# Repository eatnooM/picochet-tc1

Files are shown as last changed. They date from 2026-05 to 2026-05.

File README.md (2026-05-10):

# Picochet-TC1

A dedicated microcontroller board for use with the OpenFIRE firmware, tailored to fit in a Namco Time Crisis 1-3 or Point Blank arcade gun.

Picture of Picochet board

The goal of this project is to allow for clean builds in these guns while retaining support for driving the gun's solenoid
(not a big fan of multiple boards floating around in the shell)
and to serve as a base for future Picochet boards in other light guns where a carrier board using a Raspberry Pi Pico or similar would be tricky or impossible.

## BOM

| Reference | Part desc / number | Quantity | Notes |
|---|---|---|---|
| C1,C5,C19,C21 | 10uF 0805 - [LCSC](https://www.lcsc.com/product-detail/C95841.html) | 4 | |
| C6,C7,C9,C10 | 4.7uF 0402 - [LCSC](https://www.lcsc.com/product-detail/C23733.html) | 4 | |
| C8,C11,C12,C13,C14,C15,C16,C17,C18,C20,C26 | 0.1uF 0402 - [LCSC](https://www.lcsc.com/product-detail/C307331.html) | 11 | May want to replace C26 with a THT cap directly on the TMP36 pins |
| C3,C4 | 15pF 0402 - [LCSC](https://www.lcsc.com/product-detail/C86285.html) | 2 | |
| D1 | SOD-323F Schottky - [LCSC](https://www.lcsc.com/product-detail/C552826.html)  | 1 | |
| D2 | RBR3LAM60B - [LCSC](https://www.lcsc.com/product-detail/C509954.html) | 1 | Can also be added at D3 if your solenoid has no flyback diode |
| F1 | PPTC-6V 500mA - [LCSC](https://www.lcsc.com/product-detail/C269104.html) | 1 | |
| L1 | AOTA-B201610S3R3 - [LCSC](https://www.lcsc.com/product-detail/C42411119.html) | 1 | |
| Q1,Q2 | DMT12H060LFDF - [LCSC](https://www.lcsc.com/product-detail/C5711753.html) | 2 | |
| R2,R4,R6,R14,R16 | 1K 0402 - [LCSC](https://www.lcsc.com/product-detail/C11702.html) | 5 | |
| R15,R17 | 100K 0402 - [LCSC](https://www.lcsc.com/product-detail/C60491.html) | 2 | |
| R5 | 33Ω 0402 - [LCSC](https://www.lcsc.com/product-detail/C138002.html) | 1 | |
| R7,R8 | 27Ω 0402 - [LCSC](https://www.lcsc.com/product-detail/C138021.html) | 2 | |
| U1 | RP2354A - [LCSC](https://www.lcsc.com/product-detail/C41378174.html) | 1 | |
| U2 | NCP1117-3.3_SOT223 - [LCSC](https://www.lcsc.com/product-detail/C26537.html) | 1 | |
| Y1 | ABM8-272-T3 - [LCSC](https://www.lcsc.com/product-detail/C20625731.html) | 1 | |
| SW1,SW2 | 4x3mm push button - [LCSC](https://www.lcsc.com/product-detail/C455280.html) | 2 | |

Optional components (see Notes): 
| Reference | Part desc / number | Quantity | Notes |
|---|---|---|---|
| TMP | TMP36 - [LCSC](https://www.lcsc.com/product-detail/C5692995.html) | 1 | Recommended - run wires to this and attach to solenoid |
| C24,C25 | 0.1uF 0805 - [LCSC](https://www.lcsc.com/product-detail/C1711.html) | 2 | Installation not recommended |

## Thanks

OpenFIRE project - https://openfirelightgun.org/

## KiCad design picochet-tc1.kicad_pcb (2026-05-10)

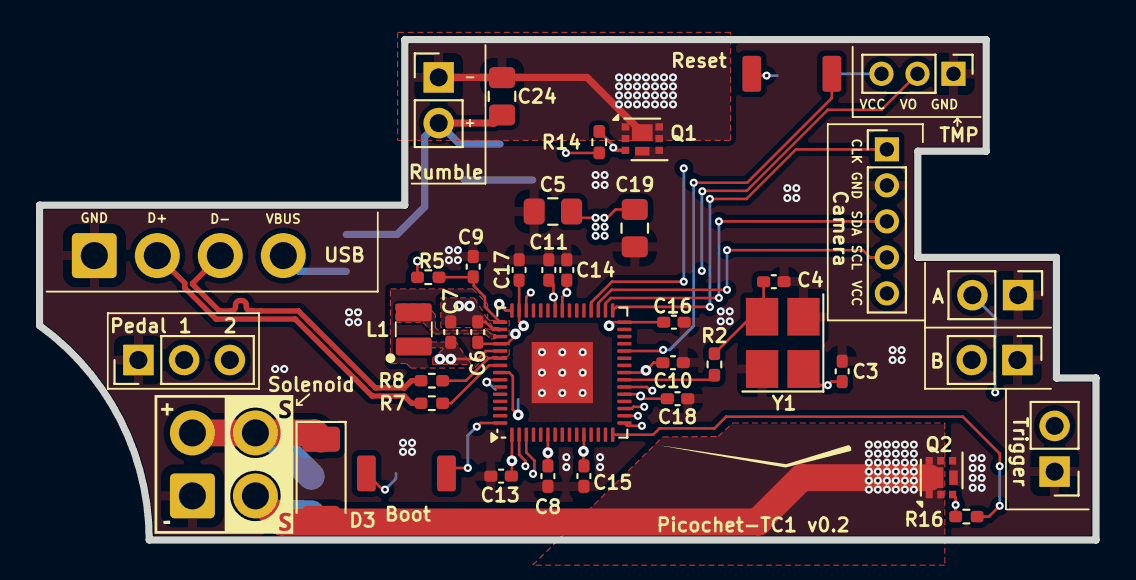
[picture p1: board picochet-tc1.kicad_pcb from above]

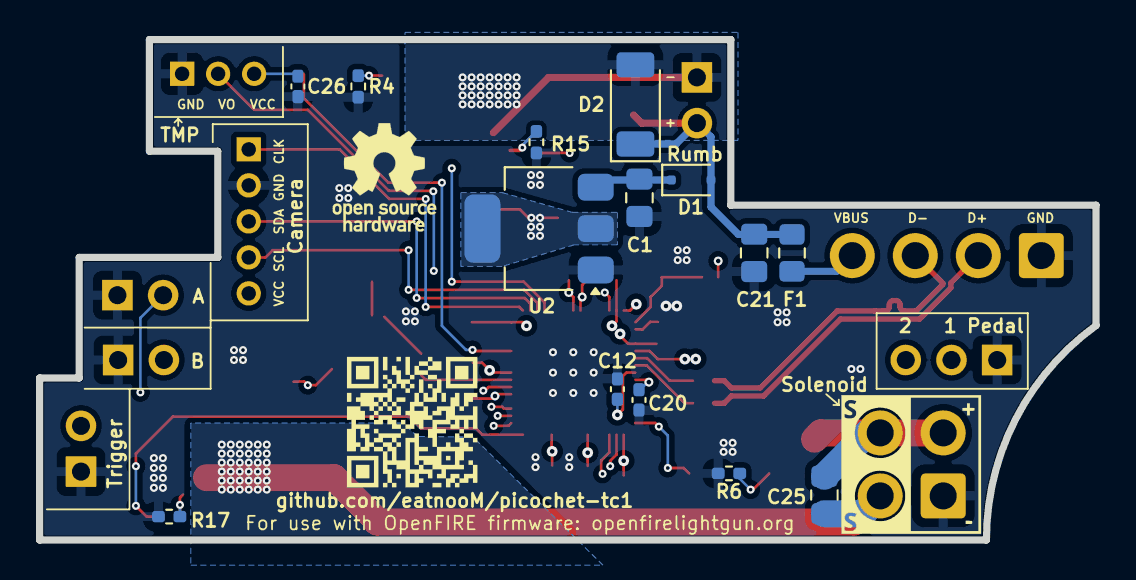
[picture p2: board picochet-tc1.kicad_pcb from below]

Board: 4 copper layers, 58.7 x 27.8 mm, 55 parts (15 on the bottom side), 35 nets.

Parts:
C1, C5, C19, C21: 10uF; C_0805_2012Metric_Pad1.18x1.45mm_HandSolder
C3, C4: 15pF; C_0402_1005Metric_Pad0.74x0.62mm_HandSolder
C6, C7, C9, C10: 4.7uF; C_0402_1005Metric_Pad0.74x0.62mm_HandSolder
C8, C11, C12, C13, C14, C15, C16, C17, C18, C20, C26: 100nF; C_0402_1005Metric_Pad0.74x0.62mm_HandSolder
C24, C25: 100nF; C_0805_2012Metric_Pad1.18x1.45mm_HandSolder
D1: D_Schottky; D_SOD-323F
D2, D3: RBR3LAM60B; D_SOD-128
F1: PPTC-6V 500mA; Fuse_0805_2012Metric_Pad1.15x1.40mm_HandSolder
J1, J2, J4, J9: Conn_01x02; PinHeader_1x02_P2.54mm_Vertical
J3: Conn_01x04; USB-PTH-2.5MMOD-3.5mmSpacing
J5: Conn_02x02; 02x02_PTH-2.5MMOD-3.5mmSpacing
J6: Conn_01x05; PinHeader_1x05_P2.00mm_Vertical
J7: Conn_01x03; PinHeader_1x03_P2.00mm_Vertical
J8: Conn_01x03; PinHeader_1x03_P2.54mm_Vertical
L1: AOTA-B201610S3R3; L_0806_PolarityMark
Q1, Q2: DMT12H060LFDF; Diodes_UDFN2020-6_Type-F
QR*****: github.com/eatnooM/picochet-tc1; picochet-tc1-repo-qr
R2, R4, R6, R14, R16: 1K; R_0402_1005Metric_Pad0.72x0.64mm_HandSolder
R5: 33R; R_0402_1005Metric_Pad0.72x0.64mm_HandSolder
R7, R8: 27R; R_0402_1005Metric_Pad0.72x0.64mm_HandSolder
R15, R17: 100K; R_0402_1005Metric_Pad0.72x0.64mm_HandSolder
SW1, SW2: SW_Push; Switch-Push-SMD-4mmx3mm
U1: RP2354A; QFN-60-1EP_7x7mm_P0.4mm_EP3.4x3.4mm
U2: NCP1117-3.3_SOT223; SOT-223-3_TabPin2
Y1: ABM8-272-T3; Crystal_SMD_3225-4Pin_3.2x2.5mm_HandSoldering

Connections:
+1V1: C7.2, C8.2, C10.2, C11.2, L1.1, U1.6 (DVDD), U1.23 (DVDD), U1.39 (DVDD), U1.50 (VREG_FB)
+3V3: C5.1, C6.2, C12.2, C13.2, C14.2, C15.2, C16.2, C17.1, C18.2, C19.1, C20.2, C26.1, J6.5, J7.3, R5.1, U1.1 (IOVDD), U1.11 (IOVDD), U1.20 (IOVDD), U1.30 (IOVDD), U1.38 (IOVDD), U1.44 (ADC_AVDD), U1.45 (IOVDD), U1.49 (VREG_VIN), U1.53 (USB_OTP_VDD), U1.54 (QSPI_IOVDD), U2.2 (VO)
+5V: C21.1, C24.2, D1.2 (A), D2.1 (K), F1.2, J1.2
/CAM_CLK: J6.1, U1.31 (GPIO19)
/CAM_SCL: J6.4, U1.33 (GPIO21)
/CAM_SDA: J6.3, U1.32 (GPIO20)
/RMB_GND: C24.1, D2.2 (A), J1.1, Q1.1 (D), Q1.2 (D), Q1.5 (D), Q1.6 (D), Q1.7 (D)
/RUMBLE: R14.1, U1.34 (GPIO22)
/SOLENOID: R16.1, U1.15 (GPIO11)
/SOL_GND: C25.1, D3.2 (A), J5.2, Q2.1 (D), Q2.2 (D), Q2.5 (D), Q2.6 (D), Q2.7 (D)
/TMP: J7.2, U1.43 (GPIO29/ADC3)
/USB_D+: J3.2, R7.1
/USB_D-: J3.3, R8.1
/VREG_LX: L1.2, U1.48 (VREG_LX)
/~BTN_A: J4.2, U1.17 (GPIO13)
/~BTN_B: J9.2, U1.18 (GPIO14)
/~BTN_PEDAL_1: J8.2, U1.2 (GPIO0)
/~BTN_PEDAL_2: J8.3, U1.3 (GPIO1)
/~BTN_TRIGGER: J2.2, U1.16 (GPIO12)
/~RESET: SW2.2, U1.26 (RUN)
GND: C1.2, C3.1, C4.1, C5.2, C6.1, C7.1, C8.1, C9.1, C10.1, C11.1, C12.1, C13.1, C14.1, C15.1, C16.1, C17.2, C18.1, C19.2, C20.1, C21.2, C26.2, J2.1, J3.1, J4.1, J5.1, J6.2, J7.1, J8.1, J9.1, Q1.4 (S), Q1.8 (S), Q2.4 (S), Q2.8 (S), R4.1, R6.1, R15.1, R17.1, U1.47 (VREG_PGND), U1.61 (GND), U2.1 (GND), Y1.2 (G), Y1.4 (G)
unnamed: C4.2, R2.1, Y1.3
unnamed: Q1.3 (G), R14.2, R15.2
unnamed: Q2.3 (G), R16.2, R17.2
unnamed: R4.2, SW2.1
unnamed: R6.2, SW1.1
unnamed: R8.2, U1.51 (USB_DM)
unnamed: R7.2, U1.52 (USB_DP)
unnamed: C3.2, U1.21 (XIN), Y1.1
unnamed: R2.2, U1.22 (XOUT)
unnamed: SW1.2, U1.60 (~QSPI_SS)
SOL_PWR: C25.2, D3.1 (K), J5.3, J5.4
VBUS: F1.1, J3.4
VREG_AVDD: C9.2, R5.2, U1.46 (VREG_AVDD)
VSYS: C1.1, D1.1 (K), U2.3 (VI)

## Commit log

2026-02-15 Add QR link to repo, cleanup
    [picochet-tc1.kicad_pcb]
2026-02-17 Small tweaks for v0.1 prototype
    [picochet-tc1.kicad_pcb, picochet-tc1.kicad_sch]
2026-02-20 Larger vias to keep JLC happy
    [picochet-tc1.kicad_pcb]
2026-02-20 swap 10uF caps to 0805; tweak routing
    [picochet-tc1.kicad_pcb, picochet-tc1.kicad_sch]
2026-05-04 Add options for second pedal and A/B buttons
    [picochet-tc1.kicad_pcb, picochet-tc1.kicad_sch]
2026-05-10 Add BOM
2026-05-10 Fix LCSC part numbers for some components
    [picochet-tc1.kicad_pcb, picochet-tc1.kicad_sch]
